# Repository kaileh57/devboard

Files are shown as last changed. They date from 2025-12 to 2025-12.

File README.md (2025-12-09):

# devboard

I've finally gotten BACK into PCB design!!

This project heavily expands on my previous work both in scope and complexity. 
It's an RP2040 devboard, which I hope to use for other projects. This was definetly outside of my comfort zone (I'm a software guy) but I got it done in the end after many many hours of routing traces :(
Looking forward to the next project, which is hopefully more complex!
It includes FOUR status LEDs, hooked up to GPIO pins 14-17
I also labeled each pin, as my past use of devboards in class has required a lot of referencing the design spec, which I hope to cut down here.

Schematic:


Design:


Render:



Feel free to use this devboard! It's MIT, but I'd appreciate at least a nod if you find it useful.

Made for Hack Club Blueprint: https://blueprint.hackclub.com/

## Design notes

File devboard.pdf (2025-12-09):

# Devboard v1.2

## RP2040 Development Platform

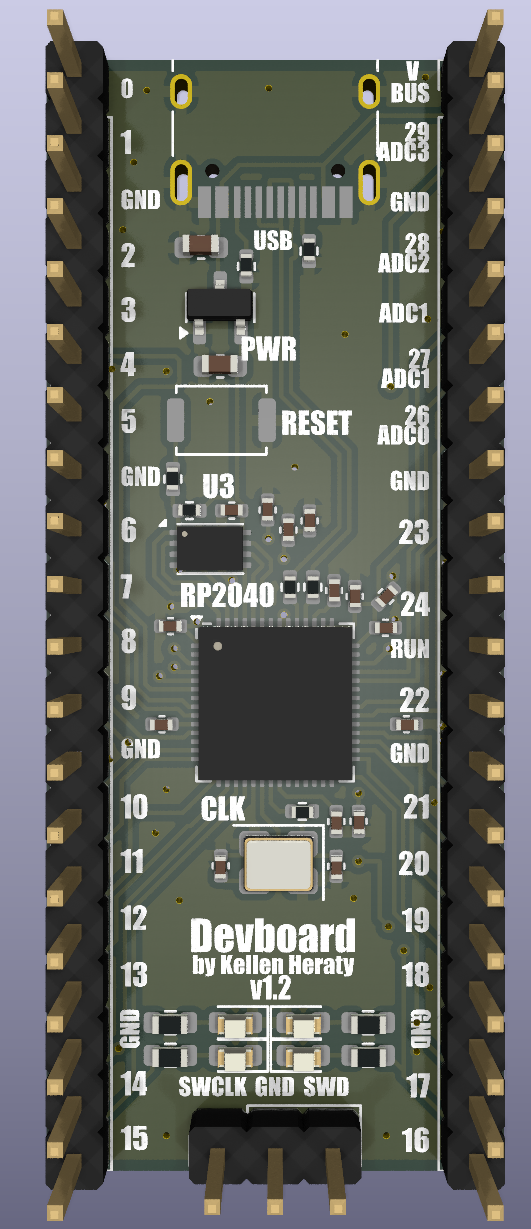
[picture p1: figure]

Designed by Kellen Heraty

https://github.com/kaileh57/devboard

Date: December 9, 2025

Rev 1.0 | Devboard v1.2 Datasheet

## Product Overview

The Devboard v1.2 is a compact, high-performance microcontroller board powered by the Raspberry Pi RP2040. It combines the power of dual Cortex-M0+ cores with a modern USB-C interface and a simplified GPIO layout.

### 1.1 Technical Specifications

- MCU: RP2040 (Dual-core ARM Cortex-M0+ @ 133MHz)
- Flash Storage: 2MB QSPI (Winbond W25Q16JV)
- SRAM: 264kB on-chip
- Power Input: 5V via USB-C
- Operating Voltage: 3.3V (Onboard MCP1700 LDO, 250mA Max)
- GPIO: 20x user-accessible pins (plus 4x LED pins)
- Dimensions: 40-pin DIP form factor (Standard 2.54mm pitch)

## Pinout & Interfaces

The board features a 40-pin header layout designed for breadboard compatibility.

Left Function | GP | Pin | Pin | GP | Right Function
UART0 TX / I2C0 SDA | 0 | 1 | 40 | VBUS | 5V Input
UART0 RX / I2C0 SCL | 1 | 2 | 39 | 29 | ADC3
Ground | GND | 3 | 38 | GND | Analog GND
I2C1 SDA | 2 | 4 | 37 | 28 | ADC2
I2C1 SCL | 3 | 5 | 36 | 27 | ADC1
SPI0 RX | 4 | 6 | 35 | 26 | ADC0
SPI0 CSn | 5 | 7 | 34 | GND | Ground
Ground | GND | 8 | 33 | 23 | User IO
SPI0 SCK | 6 | 9 | 32 | 24 | User IO
SPI0 TX | 7 | 10 | 31 | RUN | Reset/Enable
SPI1 RX | 8 | 11 | 30 | 22 | User IO
SPI1 CSn | 9 | 12 | 29 | GND | Ground
Ground | GND | 13 | 28 | 21 | I2C0 SCL
SPI1 SCK | 10 | 14 | 27 | 20 | I2C0 SDA
SPI1 TX | 11 | 15 | 26 | 19 | SPI0 TX
UART0 TX | 12 | 16 | 25 | 18 | SPI0 SCK
UART0 RX | 13 | 17 | 24 | GND | Ground
Ground | GND | 18 | 23 | 17 | LED D4
LED D1 | 14 | 19 | 22 | 16 | LED D3
LED D2 | 15 | 20 | 21 | - | (No Pin)

Table 1: Devboard v1.2 Pin Map

### 2.1 Status LEDs

Four red LEDs are connected to the lower GPIO pins. Writing HIGH to these pins turns the LED ON.

LED D1 | LED D2 | LED D3 | LED D4
GPIO 14 | GPIO 15 | GPIO 16 | GPIO 17

1

Rev 1.0 | Devboard v1.2 Datasheet

## Schematic Diagram

The following schematic details the core RP2040 connections, USB-C interface, and power regulation circuit.

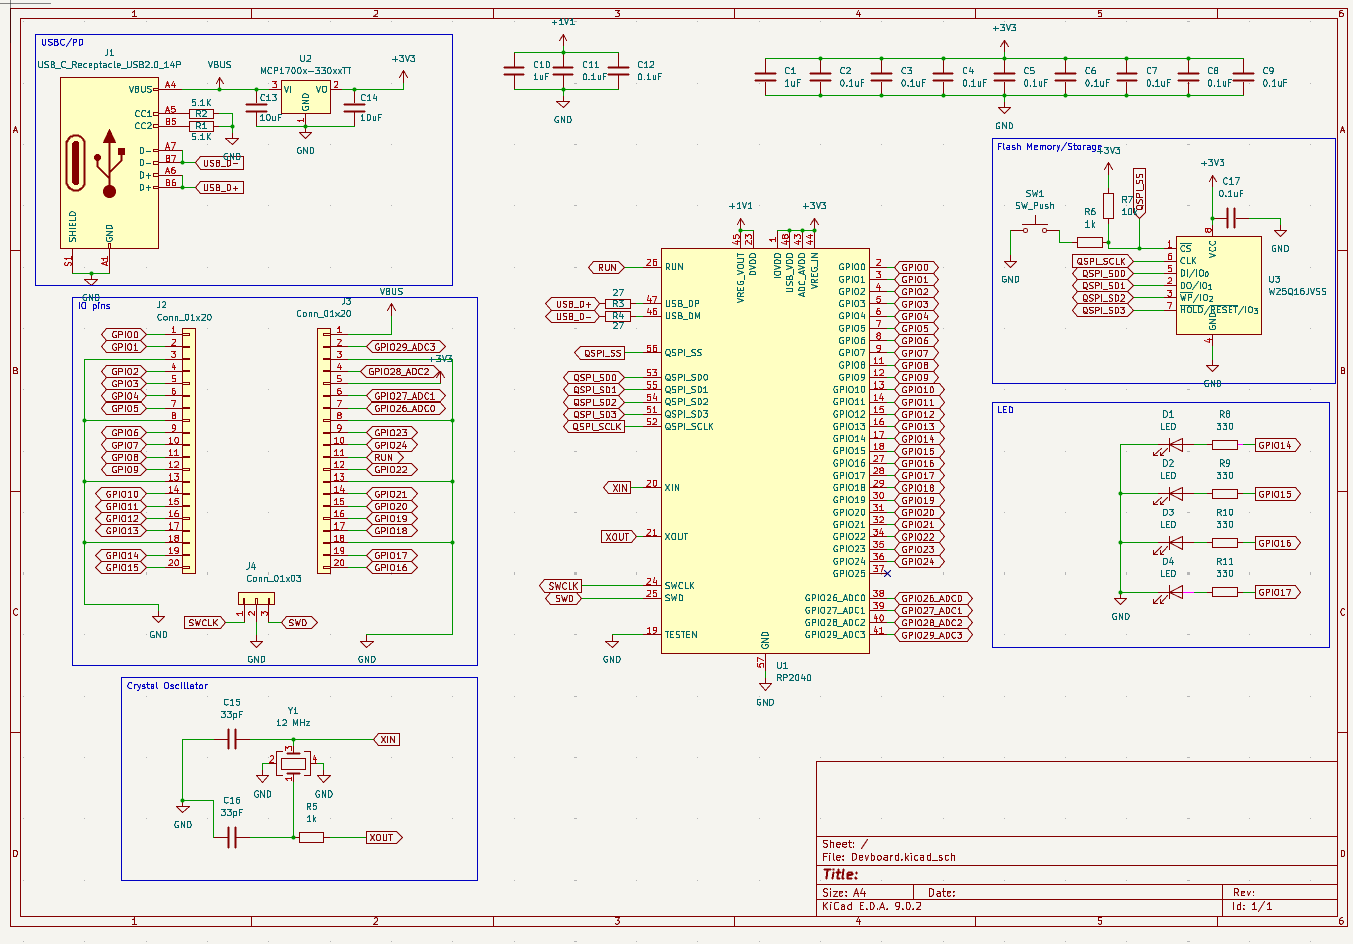
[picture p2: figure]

Figure 1: Full System Schematic

### 3.1 Design Notes

- Crystal Oscillator: 12MHz external crystal (Y1) with 33pF load capacitors.
- USB Termination: 27Ω series resistors on D+ and D- lines.
- Flash Memory: W25Q16JV connected via QSPI interface.
- Bootloader: Pulls CSn low via SW1 to enter USB Mass Storage mode.

2

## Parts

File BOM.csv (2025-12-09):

JLCPCB BOM Tool - BOM Matching
BOM name：Devboard-JLCPCB Assembly Order.xlsx |  |  | Download Time：2025-12-09 14:25:52 |  |  |  | * Our matching results are updated in real-time, but stock and prices may change. If it's been over 24 hours, please re-match before placing your order.
PCB Assembled Qty：5 |  |  | Est. Total Price：5.6637
Your BOM |  |  |  |  | Matched Parts |  |  |  |  |  |  | Order Information
Top Designator | Bottom Designator | Comment | Footprint | JLCPCB Part # | Matches | Part # | Manufacturer | Footprint | Description | Category | Warning | JLCPCB Part # | Product link | Lib Type | Qty | Source | Total Price ($)
C2,C5,C17,C4,C6,C7,C11,C12,C3,C9,C8 |  | 0.1uF | C_0402_1005Metric |  | Select by Customer | CL05B104KO5NNNC | Samsung Electro-Mechanics | 0402 | 100nF 16V X7R ±10% 0402 Multilayer Ceramic Capacitors MLCC - SMD/SMT ROHS | Multilayer Ceramic Capacitors MLCC - SMD/SMT | 1.The comment (CL05B104KO5NNNC) of this part does not match the one (0.1uF) provided in your BOM. Please confirm; | C1525 | https://jlcpcb.com/partdetail/1877-CL05B104KO5NNNC/C1525 | Basic | 22 | 22 JLCPCB | 0.0264
C10,C1 |  | 1uF | C_0402_1005Metric |  | Select by Customer | CL05A105KA5NQNC | Samsung Electro-Mechanics | 0402 | 1uF 25V X5R ±10% 0402 Multilayer Ceramic Capacitors MLCC - SMD/SMT ROHS | Multilayer Ceramic Capacitors MLCC - SMD/SMT |  | C52923 | https://jlcpcb.com/partdetail/53938-CL05A105KA5NQNC/C52923 | Basic | 4 | 4 JLCPCB | 0.0116
C14,C13 |  | 10uF | C_0603_1608Metric |  | Select by Customer | CL10A106KP8NNNC | Samsung Electro-Mechanics | 0603 | 10V 10uF X5R ±10% 0603 Multilayer Ceramic Capacitors MLCC - SMD/SMT ROHS | Multilayer Ceramic Capacitors MLCC - SMD/SMT |  | C19702 | https://jlcpcb.com/partdetail/20411-CL10A106KP8NNNC/C19702 | Basic | 4 | 4 JLCPCB | 0.0224
C15,C16 |  | 33pF | C_0402_1005Metric |  | Select by Customer | 0402CG330J500NT | FH (Guangdong Fenghua Advanced Tech) | 0402 | 33pF 50V C0G ±5% 0402 Multilayer Ceramic Capacitors MLCC - SMD/SMT ROHS | Multilayer Ceramic Capacitors MLCC - SMD/SMT |  | C1562 | https://jlcpcb.com/partdetail/1914-0402CG330J500NT/C1562 | Basic | 4 | 4 JLCPCB | 0.004
CLK |  | 12MHz | Crystal_SMD_3225-4Pin_3.2x2.5mm |  | Select by Customer | X322512MSB4SI | YXC Crystal Oscillators | SMD3225-4P | -40℃~+85℃ 12MHz 20pF Crystal Oscillator ±10ppm ±20ppm SMD3225-4P Crystals ROHS | Crystals |  | C9002 | https://jlcpcb.com/partdetail/YXC_CrystalOscillators-X322512MSB4SI/C9002 | Basic | 2 | 2 JLCPCB | 0.129
D4,D3,D2,D1 |  | LED | LED_0603_1608Metric |  | Select by Customer | KT-0603R | Hubei KENTO Elec | 0603 | -40℃~+85℃ 120° 2.4V 20mA 300mcd 40mW 615nm~630nm 645nm Red Water Clear 0603 LED Indication - Discrete ROHS | LED Indication - Discrete | 1.The comment (KT-0603R) of this part does not match the one (LED) provided in your BOM. Please confirm; | C2286 | https://jlcpcb.com/partdetail/Hubei_KENTOElec-KT0603R/C2286 | Basic | 8 | 8 JLCPCB | 0.0448
J3,J2 |  | Conn_01x20 | PinHeader_1x20_P2.54mm_Vertical |  | Select by Customer | 2.54-1*20P直针 | BOOMELE(Boom Precision Elec) | 插件,P=2.54mm | -40℃~+105℃ 1 1x20P 2.54mm 20P 3A Black Brass Pin Header Through Hole Plugin,P=2.54mm Pin Headers ROHS | Pin Headers |  | C50981 | https://jlcpcb.com/partdetail/51993-2_54_1_20P/C50981 | Extended | 0 | 0 JLCPCB | 0
J4 |  | Conn_01x03 | PinHeader_1x03_P2.54mm_Vertical |  | Select by Customer | 1.27-1*3P针 | BOOMELE(Boom Precision Elec) | 插件,P=1.27mm | -55℃~+105℃ 1 1.27mm 1mm 1x3P 2.3mm 3A 3P 3mm Black Brass Pin Header Through Hole Plugin,P=1.27mm Pin Headers ROHS | Pin Headers |  | C24980 | https://jlcpcb.com/partdetail/25717-1_27_1_3P/C24980 | Extended | 0 | 0 JLCPCB | 0
PWR |  | MCP1700x-330xxTT | SOT-23 |  | Select by Customer | MCP1700T-3302E/TT | Microchip Tech | SOT-23 | -40℃~+125℃@(Tj) 1 1.6uA 178mV@(250mA) 250mA 3.3V 44dB@(100Hz) 6V Fixed Over Temperature Protection Positive SOT-23 Voltage Regulators - Linear, Low Drop Out (LDO) Regulators ROHS | Voltage Regulators - Linear, Low Drop Out (LDO) Regulators |  | C39051 | https://jlcpcb.com/partdetail/MicrochipTech-MCP1700T_3302ETT/C39051 | Extended | 5 | 5 JLCPCB | 1.9695
R1,R2 |  | 5.1K | R_0402_1005Metric |  | Select by Customer | 0402WGF5101TCE | UNI-ROYAL(Uniroyal Elec) | 0402 | -55℃~+155℃ 5.1kΩ 50V 62.5mW Thick Film Resistor ±1% ±100ppm/℃ 0402 Chip Resistor - Surface Mount ROHS | Chip Resistor - Surface Mount |  | C25905 | https://jlcpcb.com/partdetail/26648-0402WGF5101TCE/C25905 | Basic | 4 | 4 JLCPCB | 0.002
R4,R3 |  | 27 | R_0402_1005Metric |  | Select by Customer | 0402WGF270JTCE | UNI-ROYAL(Uniroyal Elec) | 0402 | -55℃~+155℃ 27Ω 50V 62.5mW Thick Film Resistor ±1% ±100ppm/℃ 0402 Chip Resistor - Surface Mount ROHS | Chip Resistor - Surface Mount | 1.The comment (0402WGF270JTCE) of this part does not match the one (27) provided in your BOM. Please confirm; | C25100 | https://jlcpcb.com/partdetail/25843-0402WGF270JTCE/C25100 | Extended | 20 | 20 JLCPCB | 0.012
R6,R5 |  | 1k | R_0402_1005Metric |  | Select by Customer | 0402WGF1001TCE | UNI-ROYAL(Uniroyal Elec) | 0402 | -55℃~+155℃ 1kΩ 50V 62.5mW Thick Film Resistor ±1% ±100ppm/℃ 0402 Chip Resistor - Surface Mount ROHS | Chip Resistor - Surface Mount | 1.The comment (0402WGF1001TCE) of this part does not match the one (1k) provided in your BOM. Please confirm; | C11702 | https://jlcpcb.com/partdetail/12256-0402WGF1001TCE/C11702 | Basic | 4 | 4 JLCPCB | 0.0024
R7 |  | 10k | R_0402_1005Metric |  | Select by Customer | 0402WGF1002TCE | UNI-ROYAL(Uniroyal Elec) | 0402 | -55℃~+155℃ 10kΩ 50V 62.5mW Thick Film Resistor ±1% ±100ppm/℃ 0402 Chip Resistor - Surface Mount ROHS | Chip Resistor - Surface Mount | 1.The comment (0402WGF1002TCE) of this part does not match the one (10k) provided in your BOM. Please confirm; | C25744 | https://jlcpcb.com/partdetail/26487-0402WGF1002TCE/C25744 | Basic | 2 | 2 JLCPCB | 0.001
R11,R10,R9,R8 |  | 330 | R_0603_1608Metric |  | Select by Customer | 0603WAF3300T5E | UNI-ROYAL(Uniroyal Elec) | 0603 | -55℃~+155℃ 100mW 330Ω 75V Thick Film Resistor ±1% ±100ppm/℃ 0603 Chip Resistor - Surface Mount ROHS | Chip Resistor - Surface Mount | 1.The comment (0603WAF3300T5E) of this part does not match the one (330) provided in your BOM. Please confirm; | C23138 | https://jlcpcb.com/partdetail/23865-0603WAF3300T5E/C23138 | Basic | 8 | 8 JLCPCB | 0.0088
RESET |  | SW_Push | SW_Push_SPST_NO_Alps_SKRK |  | Select by Customer | TS-1088-AR02016 | XUNPU | SMD,4x3mm | -30℃~+80℃ 1.6N 100,000 Cycles 12V 2mm 3mm 4mm 50mA Black Round Button SMD(SMT) Tab SPST Surface Mount,Vertical Without Bracket SMD,4x3mm Tactile Switches ROHS | Tactile Switches |  | C720477 | https://jlcpcb.com/partdetail/XUNPU-TS_1088AR02016/C720477 | Basic | 2 | 2 JLCPCB | 0.085
RP2040 |  | RP2040 | QFN-56-1EP_7x7mm_P0.4mm_EP3.2x3.2mm |  | Select by Customer | RP2040 | Raspberry Pi | LQFN-56(7x7) | 12bit 133MHz 30 LQFN-56(7x7) Microcontrollers (MCU/MPU/SOC) ROHS | Microcontrollers (MCU/MPU/SOC) |  | C2040 | https://jlcpcb.com/partdetail/RaspberryPi-RP2040/C2040 | Extended | 2 | 2 JLCPCB | 1.833
U3 |  | W25Q16JVSS | Winbond_USON-8-1EP_3x2mm_P0.5mm_EP0.2x1.6mm |  | Select by Customer | W25Q16JVUXIQ | Winbond Elec | USON-8-EP(2x3) | -40℃~+85℃ 100,000 Cycles 10uA 133MHz 16Mbit 2.7V~3.6V 20 Years 3ms SPI USON-8-EP(2x3) NOR FLASH ROHS | NOR FLASH | 1.The comment (W25Q16JVUXIQ) of this part does not match the one (W25Q16JVSS) provided in your BOM. Please confirm; | C2843335 | https://jlcpcb.com/partdetail/WinbondElec-W25Q16JVUXIQ/C2843335 | Extended | 2 | 2 JLCPCB | 1.173
USB |  | USB_C_Receptacle_USB2.0_14P | USB_C_Receptacle_HRO_TYPE-C-31-M-12 |  | Select by Customer | TYPE-C-31-M-12 | Korean Hroparts Elec | SMD | 1 16P 5A Female Type-C SMD USB Connectors ROHS | USB Connectors |  | C165948 | https://jlcpcb.com/partdetail/Korean_HropartsElec-TYPE_C_31_M12/C165948 | Extended | 2 | 2 JLCPCB | 0.3388

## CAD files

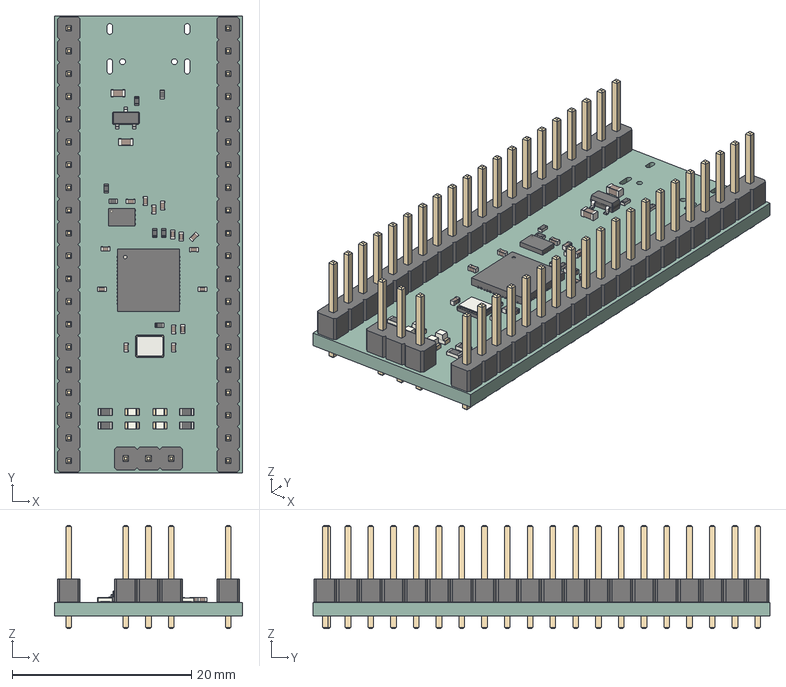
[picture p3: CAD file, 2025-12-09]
PCB/Devboard.step
21.0 x 51.0 x 11.5 mm
LED_0603_1608Metric x 4
C_0402_1005Metric x 15
R_0402_1005Metric x 7
C_0603_1608Metric x 2
R_0603_1608Metric x 4
PinHeader_1x20_P2.54mm_Vertical x 2
SOT-23
PinHeader_1x03_P2.54mm_Vertical
Crystal_SMD_3225-4Pin_3.2x2.5mm
Winbond_USON-8-1EP_3x2mm_P0.5mm_EP0.2x1.6mm
QFN-56-1EP_7x7mm_P0.4mm_EP3.2x3.2mm
Devboard_PCB

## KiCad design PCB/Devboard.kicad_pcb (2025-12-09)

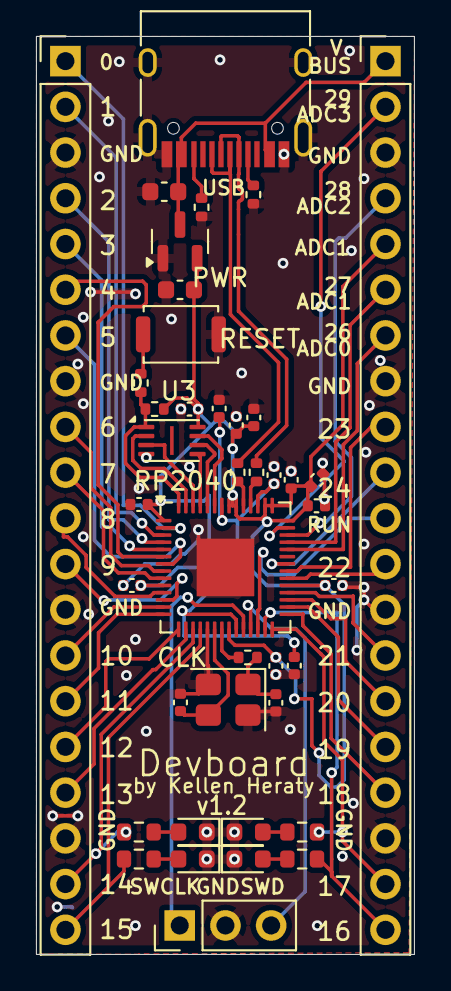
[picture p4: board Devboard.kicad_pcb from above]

Board: 2 copper layers, 21.0 x 51.0 mm, 41 parts (0 on the bottom side), 56 nets.

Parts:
C1, C10: 1uF; C_0402_1005Metric
C2, C3, C4, C5, C6, C7, C8, C9, C11, C12, C17: 0.1uF; C_0402_1005Metric
C13, C14: 10uF; C_0603_1608Metric
C15, C16: 33pF; C_0402_1005Metric
CLK: 12 MHz; Crystal_SMD_3225-4Pin_3.2x2.5mm
D1, D2, D3, D4: LED; LED_0603_1608Metric
J2, J3: Conn_01x20; PinHeader_1x20_P2.54mm_Vertical
J4: Conn_01x03; PinHeader_1x03_P2.54mm_Vertical
PWR: MCP1700x-330xxTT; SOT-23
R1, R2: 5.1K; R_0402_1005Metric
R3, R4: 27; R_0402_1005Metric
R5, R6: 1k; R_0402_1005Metric
R7: 10k; R_0402_1005Metric
R8, R9, R10, R11: 330; R_0603_1608Metric
RESET: SW_Push; SW_Push_SPST_NO_Alps_SKRK
RP2040: RP2040; QFN-56-1EP_7x7mm_P0.4mm_EP3.2x3.2mm
U3: W25Q16JVSS; Winbond_USON-8-1EP_3x2mm_P0.5mm_EP0.2x1.6mm
USB: USB_C_Receptacle_USB2.0_14P; USB_C_Receptacle_HRO_TYPE-C-31-M-12

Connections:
+1V1: C10.1, C11.1, C12.1, RP2040.23 (DVDD), RP2040.45 (VREG_VOUT), RP2040.50 (DVDD)
+3V3: C1.1, C2.1, C3.1, C4.1, C5.1, C6.1, C7.1, C8.1, C9.1, C14.1, C17.1, J3.5, PWR.2 (VO), R7.1, RP2040.1 (IOVDD), RP2040.10 (IOVDD), RP2040.22 (IOVDD), RP2040.33 (IOVDD), RP2040.42 (IOVDD), RP2040.43 (ADC_AVDD), RP2040.44 (VREG_IN), RP2040.48 (USB_VDD), RP2040.49 (IOVDD), U3.8 (VCC)
GND: C1.2, C2.2, C3.2, C4.2, C5.2, C6.2, C7.2, C8.2, C9.2, C10.2, C11.2, C12.2, C13.2, C14.2, C15.1, C16.1, C17.2, CLK.2, CLK.4, D1.1 (K), D2.1 (K), D3.1 (K), D4.1 (K), J2.3, J2.8, J2.13, J2.18, J3.3, J3.8, J3.13, J3.18, J4.2, PWR.1 (GND), R1.2, R2.2, RESET.1, RP2040.19 (TESTEN), RP2040.57 (GND), U3.4 (GND), USB.A1 (GND), USB.A12 (GND), USB.B1 (GND), USB.B12 (GND), USB.S1 (SHIELD)
GPIO0: J2.1, RP2040.2 (GPIO0)
GPIO1: J2.2, RP2040.3 (GPIO1)
GPIO2: J2.4, RP2040.4 (GPIO2)
GPIO3: J2.5, RP2040.5 (GPIO3)
GPIO4: J2.6, RP2040.6 (GPIO4)
GPIO5: J2.7, RP2040.7 (GPIO5)
GPIO6: J2.9, RP2040.8 (GPIO6)
GPIO7: J2.10, RP2040.9 (GPIO7)
GPIO8: J2.11, RP2040.11 (GPIO8)
GPIO9: J2.12, RP2040.12 (GPIO9)
GPIO10: J2.14, RP2040.13 (GPIO10)
GPIO11: J2.15, RP2040.14 (GPIO11)
GPIO12: J2.16, RP2040.15 (GPIO12)
GPIO13: J2.17, RP2040.16 (GPIO13)
GPIO14: J2.19, R8.2, RP2040.17 (GPIO14)
GPIO15: J2.20, R9.2, RP2040.18 (GPIO15)
GPIO16: J3.20, R10.2, RP2040.27 (GPIO16)
GPIO17: J3.19, R11.2, RP2040.28 (GPIO17)
GPIO18: J3.17, RP2040.29 (GPIO18)
GPIO19: J3.16, RP2040.30 (GPIO19)
GPIO20: J3.15, RP2040.31 (GPIO20)
GPIO21: J3.14, RP2040.32 (GPIO21)
GPIO22: J3.12, RP2040.34 (GPIO22)
GPIO23: J3.9, RP2040.35 (GPIO23)
GPIO24: J3.10, RP2040.36 (GPIO24)
GPIO26_ADC0: J3.7, RP2040.38 (GPIO26_ADC0)
GPIO27_ADC1: J3.6, RP2040.39 (GPIO27_ADC1)
GPIO28_ADC2: J3.4, RP2040.40 (GPIO28_ADC2)
GPIO29_ADC3: J3.2, RP2040.41 (GPIO29_ADC3)
unnamed: C16.2, CLK.1, R5.1
unnamed: D1.2 (A), R8.1
unnamed: D2.2 (A), R9.1
unnamed: D3.2 (A), R10.1
unnamed: D4.2 (A), R11.1
unnamed: R2.1, USB.A5 (CC1)
unnamed: R1.1, USB.B5 (CC2)
unnamed: R6.2, RESET.2
unnamed: R4.1, RP2040.46 (USB_DM)
unnamed: R3.1, RP2040.47 (USB_DP)
QSPI_SCLK: RP2040.52 (QSPI_SCLK), U3.6 (CLK)
QSPI_SD0: RP2040.53 (QSPI_SD0), U3.5 (DI/IO_{0})
QSPI_SD1: RP2040.55 (QSPI_SD1), U3.2 (DO/IO_{1})
QSPI_SD2: RP2040.54 (QSPI_SD2), U3.3 (~WP/IO_{2})
QSPI_SD3: RP2040.51 (QSPI_SD3), U3.7 (~HOLD/~RESET/IO_{3})
QSPI_SS: R6.1, R7.2, RP2040.56 (QSPI_SS), U3.1 (~CS)
RUN: J3.11, RP2040.26 (RUN)
SWCLK: J4.1, RP2040.24 (SWCLK)
SWD: J4.3, RP2040.25 (SWD)
USB_D+: R3.2, USB.A6 (D+), USB.B6 (D+)
USB_D-: R4.2, USB.A7 (D-), USB.B7 (D-)
VBUS: C13.1, J3.1, PWR.3 (VI), USB.A4 (VBUS), USB.A9 (VBUS), USB.B4 (VBUS), USB.B9 (VBUS)
XIN: C15.2, CLK.3, RP2040.20 (XIN)
XOUT: R5.2, RP2040.21 (XOUT)

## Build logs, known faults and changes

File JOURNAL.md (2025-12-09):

# 10/20/25 Laid out the schematic

Following the devboard tutorial to hopefully learn some real skills!
I made quite a few mistakes, but in the end the ERC is finally showing clear (well apart from the errors the tutorial told me to ignore)
I THINK i wired everything correctly, if you see something wrong lmk on slack! :)+

Pretty sure this is technically better than a pico cuz it has more IO

# 11/27/25 Applied footprints!

Assigned footprints, also fixed a minor issue with the crystal oscillator...

Took a while as I originally had named stuff in a slightly unserious way and ended up having to redo the names.

It's also been a while since i touched this project, but I finally have time!

# 11/27/25 Routed the PCB

Routed the PCB!!

Took MANY attempts to get it right, and a whole bunch of trial and error, but the DRC now passes! apart from like a billion warnings.
Next time is silkscreen

# 11/28/25 Finished up!


Made some minor tweaks and did all the silkscreening, plus the hell that is JLCPCB :)

Everything SHOULD be ready to order (i hope), and its time to move on to bigger and better things!
Things that just might be powered by this devboard...

# 12/8/25 Added LEDs!
To make the project a bit more unique, I added 4 LEDs! The LEDs are attached to GPIO pins 14-17, and are designed for that voltage (3.3v).
These LEDs can either be a fun blinker for data flow, or an actual built in programmable status LED, and wait, there's four!!





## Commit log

2025-11-29 Add journal entries for PCB project progress
    Documented the progress and updates on the PCB project, including schematic layout, footprint application, routing, and final adjustments.
2025-11-30 Add schematic image to README
    Added schematic image to the README for reference.
2025-12-09 added LEDs
    [BOM.csv, Devboard.kicad_pcb, Devboard.kicad_sch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]
2025-12-09 Add 4 LEDs for status indication and data flow
    Added 4 LEDs to the project for enhanced functionality, connected to GPIO pins 14-17, allowing for blinking or programmable status indication.
